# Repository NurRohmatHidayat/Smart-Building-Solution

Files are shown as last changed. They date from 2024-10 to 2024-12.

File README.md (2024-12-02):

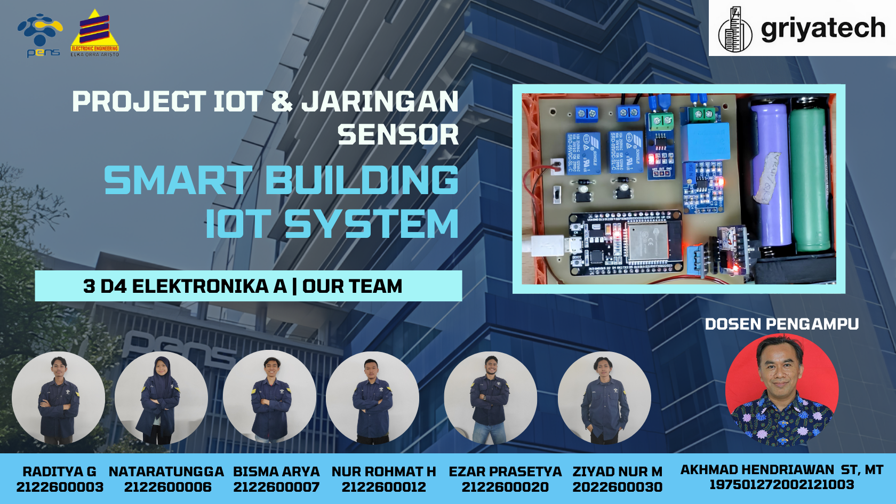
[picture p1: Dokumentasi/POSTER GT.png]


# GriyaTech
## Smart-Building-System-Berbasis IoT

Proyek ini bertujuan untuk mengembangkan sistem automasi cerdas berbasis IoT untuk Smart Building, menggunakan komponen utama seperti ESP32, RTC, dan berbagai sensor. ESP32 bertindak sebagai mikroprosesor utama yang mengontrol komunikasi antar sensor dan perangkat, memungkinkan pemantauan dan pengontrolan secara real-time melalui jaringan Wi-Fi. Sistem ini dilengkapi dengan RTC (Real-Time Clock) untuk menjaga sinkronisasi waktu, serta sensor suhu DHT11 yang digunakan untuk mengoptimalkan pengaturan suhu dan kelembaban di dalam gedung.

Untuk memantau konsumsi energi, digunakan sensor arus ACS712 dan sensor tegangan ZMPT101B yang secara akurat mengukur penggunaan listrik dan tegangan pada berbagai perangkat. Selain itu, Relay SPDT (3A 3,3V) berfungsi sebagai saklar otomatis yang memungkinkan pengendalian perangkat elektronik seperti lampu dan sistem pendingin. 

Dengan bantuan teknologi IoT, seluruh data dari sensor-sensor ini dikirimkan ke platform cloud, memungkinkan pemilik gedung untuk memantau penggunaan energi dan kondisi lingkungan secara langsung dari aplikasi mobile. Sistem ini dirancang untuk meningkatkan efisiensi energi, kenyamanan, serta keamanan penghuni gedung dengan mengotomatiskan berbagai fungsi dan memberikan kendali yang lebih fleksibel.

## Support By :
>- Dosen Pengampu : Akhmad Hendriawan ST., MT. (NIP.197501272002121003)
>- Mata kuliah : IoT dan Jaringan Sensor
>- Program Studi : D4 Teknik Elektronika
>- Politeknik Elektronika Negeri Surabaya<br>

## Team Member :
| NRP | Nama | Jobdesk | Akun |
| :---:|:---:| :---:| :-----:|
| 2122600003 | Raditya Giananta  | Hardware Developer | [Radit](https://github.com/Raditya-G)
| 2122600006 | Nataratungga Xina T | UI/UX Designer | [Ratu](https://github.com/nataratungga)
| 2122600007 | Bisma Arya Putra | Programmer | [Bisma](https://github.com/Bismaap)
| 2122600012 | Nur Rohmat Hidayat | Project Manager | [Rohmat](https://github.com/NurRohmatHidayat)
| 2122600020 | Ezar Prasetya | UI/UX Designer | [Ezar](https://github.com/EzarPrasetya)
| 2122600030 | Ziyad Nur Muhammad | 3D Designer |[Ziyad](https://github.com/Yadnur)

#### Preview Video Produk

https://github.com/user-attachments/assets/8750dca7-19aa-41fc-97a8-4954fc9a0d99

#### Preview Video Iklan 

https://github.com/user-attachments/assets/dadaf9dd-aac7-4402-b66a-3c4db6aee498

#### Preview Slide Presentasi

- [Slide Presentasi PDF](https://github.com/NurRohmatHidayat/Smart-Building-Solution/tree/main/Assets)

## Daftar Isi
- [Komponen Yang Digunakan](#Komponen-Yang-Digunakan)
- [Wiring Plan](#Wiring-Plan)
- [Hardware](#Hardware)
- [Desain 3D](#Desain-3D)
- [Program ESP32](#Program-ESP32)
- [Program Design UI/UX](#Pogram-Design-UI/UX)

## Komponen Yang Digunakan
1. **Hardware**<br>
    a. ESP32<br>
    b. Shield PCB<br>
    c. RTC<br>
    d. Sensor Suhu DHT11<br>
    e. Sensor Arus ACS712<br>
    f. Sensor Tegangan (ZMPT101B)<br>
    g. Relay SPDT (3A 3,3V)<br>

2. **Software**<br>
    a. Arduino ide<br>
    b. KiCad<br>
    c. Inventor<br>
    d. Visual Studio Code (VSC)<br>
    e. Eagle<br>

3. **Alat**<br>
    a. Solder<br>
    b. Timah solder<br>
    c. Kabel jumper<br>
    d. Breadboard<br>
    e. Obeng<br>
 
## Wiring Plan
>- First Floor Plan
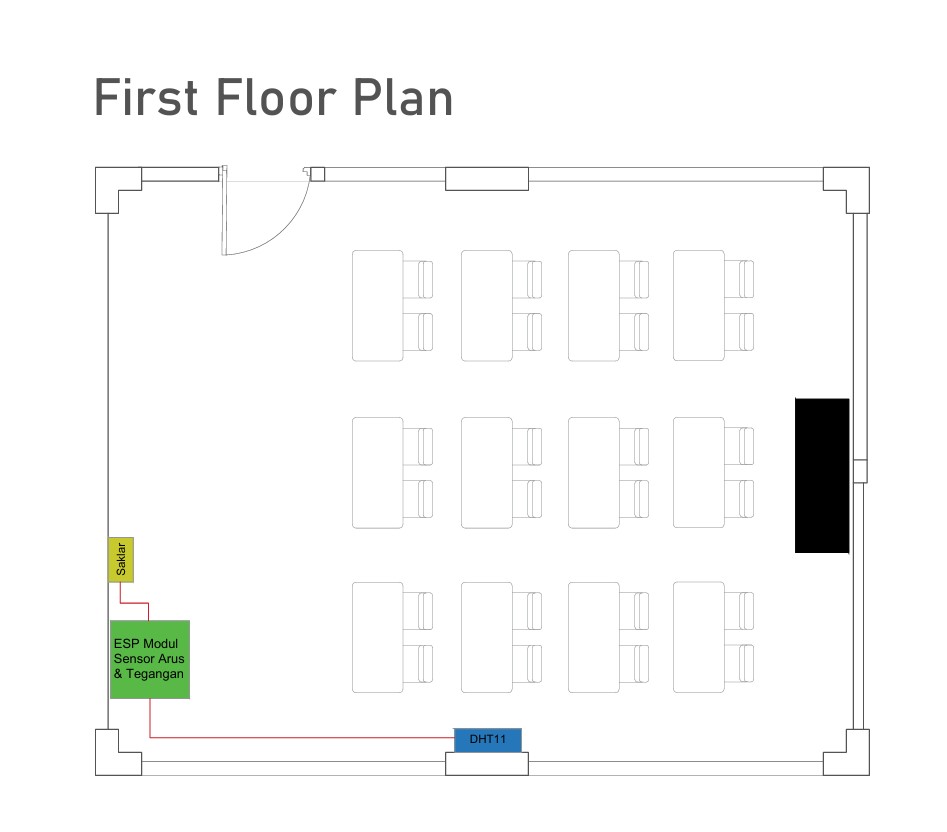
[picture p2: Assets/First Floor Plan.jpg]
>- 
>- Second Floor Plan
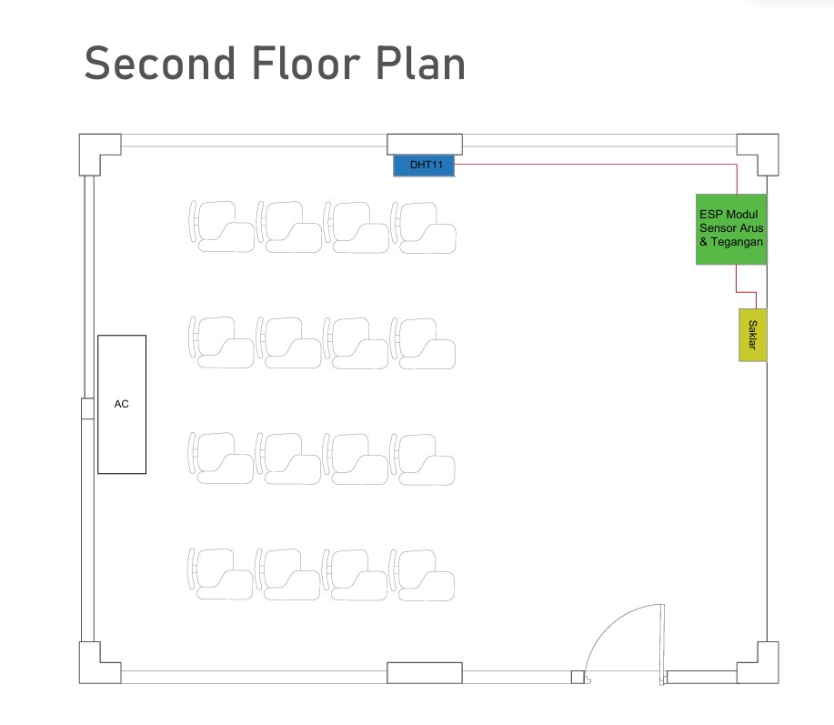
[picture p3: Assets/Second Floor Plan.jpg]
>- 

## Link YouTube 

Link youtube video produk
https://youtu.be/4Z63st0WbLA

Link youtube video iklan
https://youtu.be/mOYy9-KewV4

## [Hardware](https://github.com/NurRohmatHidayat/Smart-Building-Solution/tree/main/Hardware)

Berikut ini adalah hasil skematik rangkaian Smart Building System IoT menggunakan software KiCad.
<div align="center">
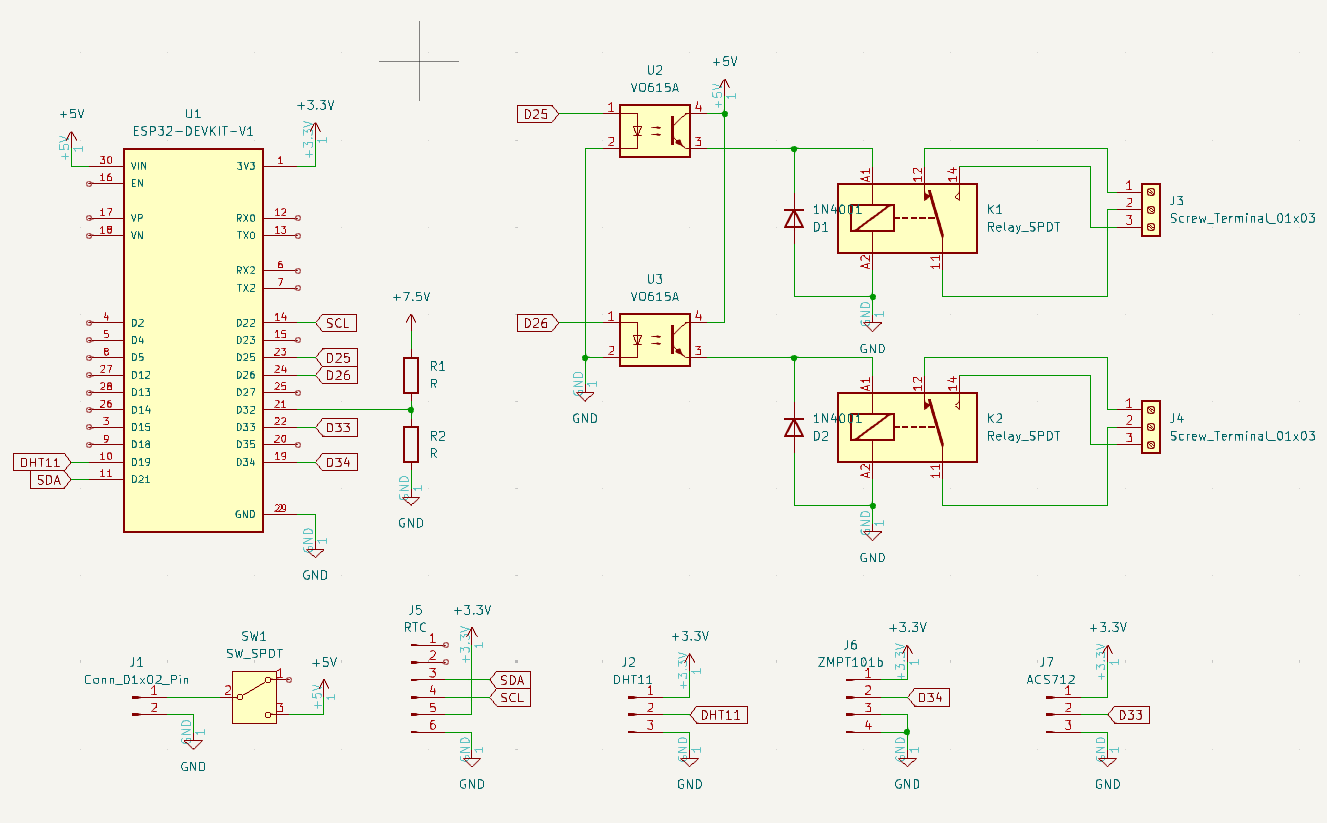
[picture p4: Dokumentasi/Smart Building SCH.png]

</div>

Berikut ini adalah hasil 3D dari  rangkaian Smart Building System IoT menggunakan software KiCad.
<div align="center">
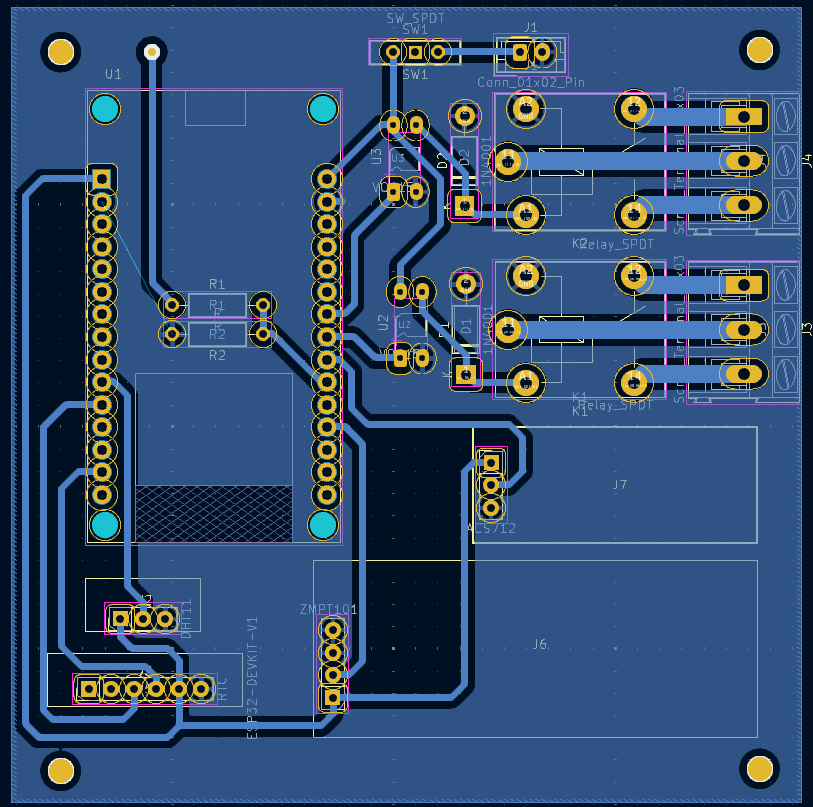
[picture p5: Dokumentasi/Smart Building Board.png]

</div>

Berikut ini adalah hasil 3D dari  rangkaian Smart Building System IoT menggunakan software KiCad.
<div align="center">
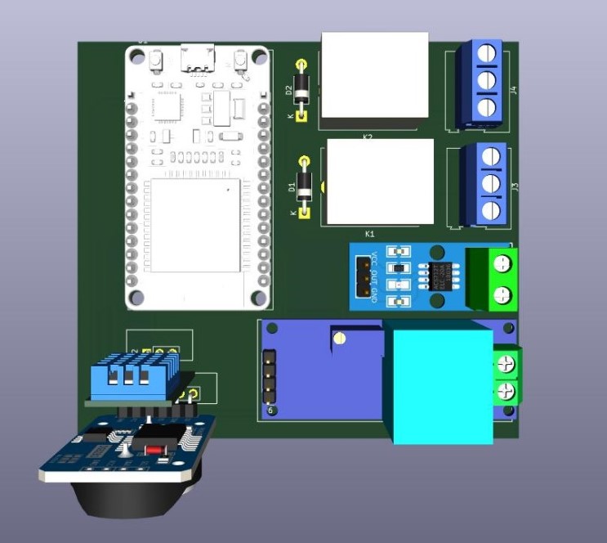
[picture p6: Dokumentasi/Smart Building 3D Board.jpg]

</div>

## [Desain 3D](https://github.com/NurRohmatHidayat/Smart-Building-Solution/tree/main/Desain%203D)

## Preview Video 3D Design

https://github.com/user-attachments/assets/e34dfbfa-0edd-4161-8904-f4dbc712b04a

Berikut adalah Link Thingivers Design 3D. Asset 3D bisa didownload pada link [Thingivers](https://www.thingiverse.com/thing:6796394)

## Diagram Block
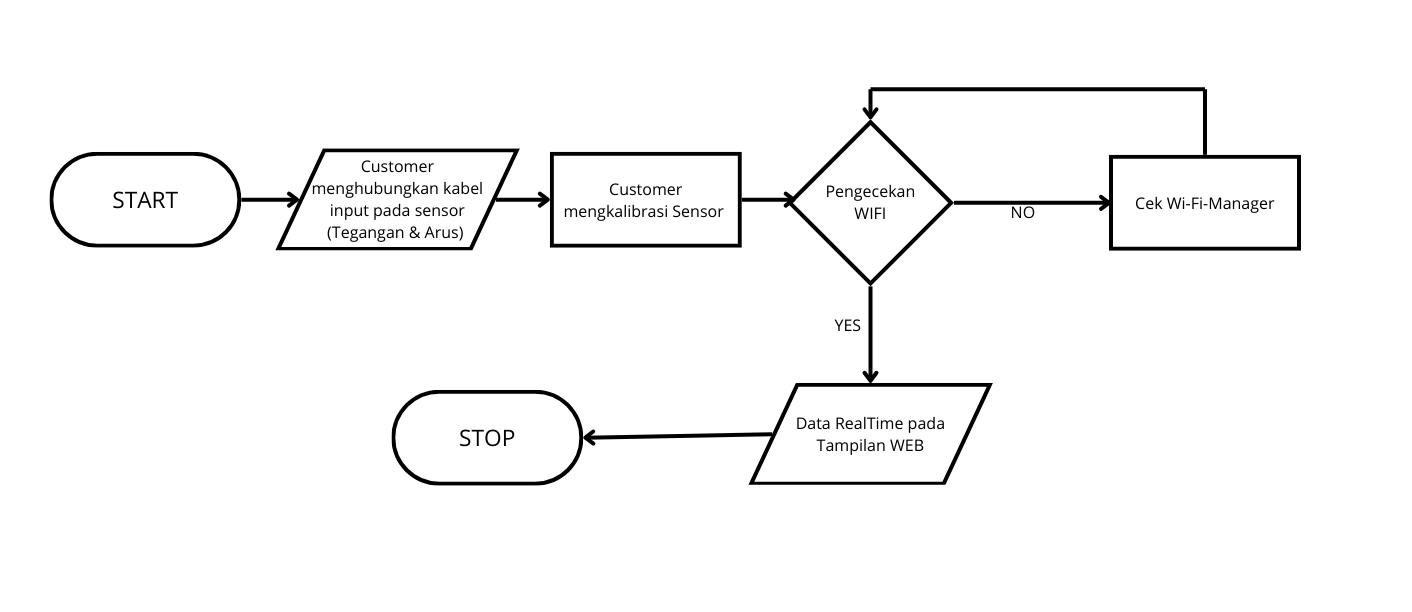
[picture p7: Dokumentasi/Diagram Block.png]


## Diagram Arsitektur System
Berikut adalah alur Diagram untuk mengirim data sensor dari publisher ke database
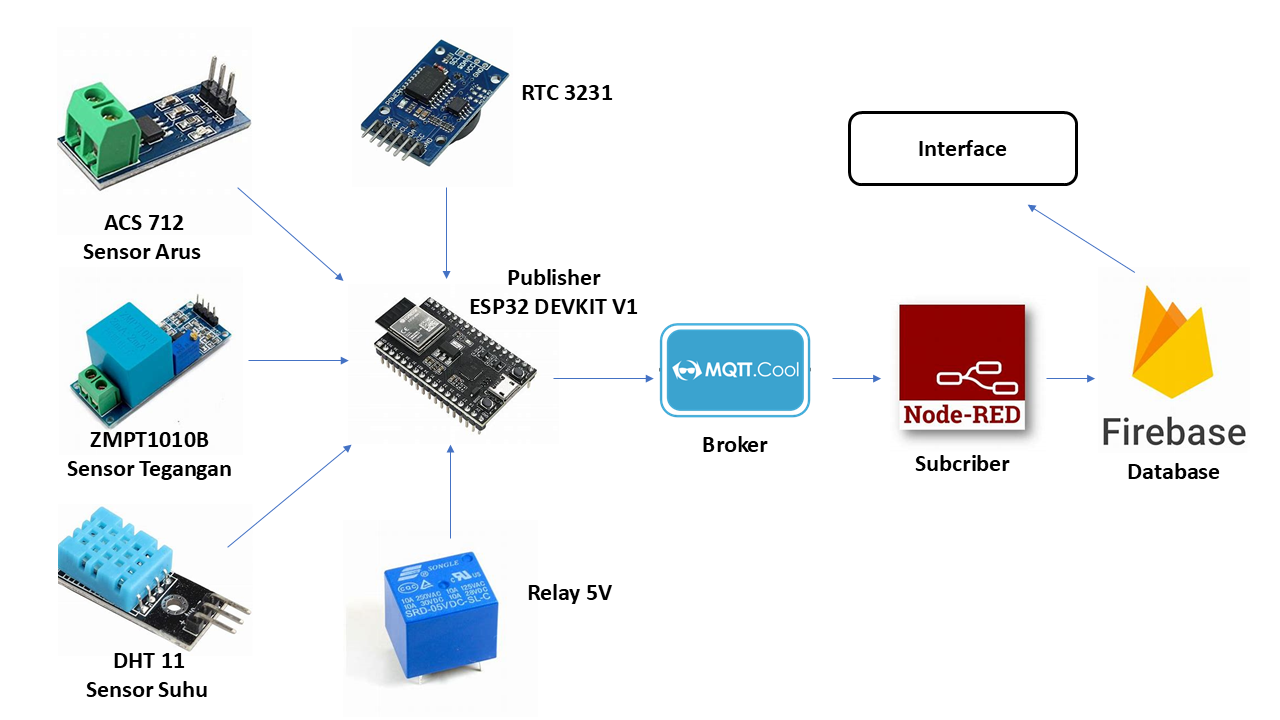
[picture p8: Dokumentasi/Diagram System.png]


## Preview Penggunaan OTA

<div align="center">

</div>

## Program ESP32

Program utama dari projek ini :
- [Arduino dengan C](https://github.com/NurRohmatHidayat/Smart-Building-Solution/tree/main/Program%20ESP32/Smart%20Building/Smart%20Building/src)

Berikut adalah video demontrasi prototype hardware. 

https://github.com/user-attachments/assets/7abacf07-8daf-47ce-86e2-667d23beedc0

Simulasi ini kami menggunakan ESP32 untuk mengontrol sensor dan modul yang terhubung di breadboard. Simulasi dilakukan menggunakan Wokwi, yang memudahkan pengujian rangkaian secara virtual sebelum implementasi fisik. Rangkaian melibatkan sensor DHT11, modul relay, LED indikator, potensiometer, dan RTC untuk sinkronisasi waktu.

Relay digunakan untuk mengontrol perangkat eksternal, sementara LED menunjukkan status sistem. Simulasi ini membantu dalam debugging dan memastikan komunikasi antar komponen berjalan baik. Meskipun Wokwi tidak menyediakan semua komponen, platform ini sangat berguna untuk pengujian dan visualisasi fungsi dasar rangkaian, membantu mengidentifikasi masalah sebelum produksi fisik.

Berikut adalah video demontrasi alat menggunakan wokwi. Klik link [Video Simulasi Software](https://youtu.be/oXDYyiHHBaU "Video Simulasi Software")

## [Alur Komunikasi]

Pada proyek ini, ESP32 menggunakan Wi-Fi Manager untuk mempermudah proses koneksi ke jaringan Wi-Fi. Wi-Fi Manager memungkinkan pengguna untuk memilih dan menghubungkan ESP32 ke jaringan internet tanpa harus mengubah kode sumber setiap kali ada perubahan pada jaringan.
Berikut tampilan pada wifi manager untuk menghubungkan ESP32 ke jaringan internet

<div align="center">
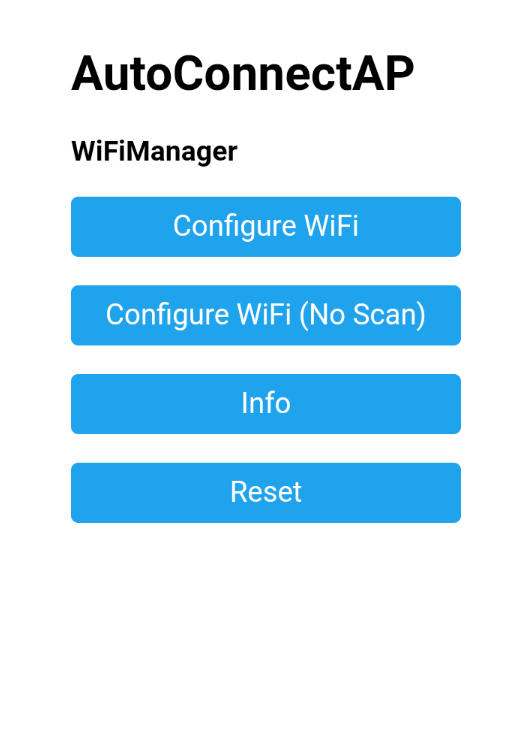
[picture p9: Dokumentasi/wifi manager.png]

</div>

Setelah ESP32 terhubung ke internet, modul ini akan mengirim data secara berkala ke broker MQTT (dalam hal ini menggunakan broker Cool MQTT). Broker MQTT berfungsi sebagai perantara yang memungkinkan ESP32 mengirim data ke sistem lain dalam arsitektur ini.
berikut tampilan broker.mqtt.cool yang menerima data sensor dari publisher ESP32
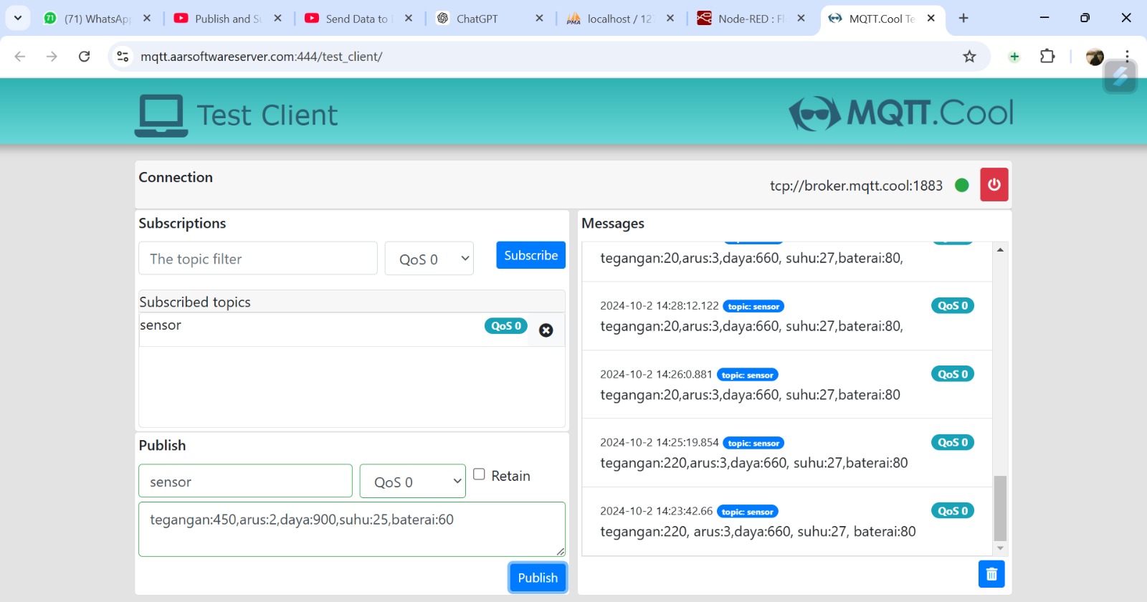
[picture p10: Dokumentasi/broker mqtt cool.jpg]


Node-RED digunakan sebagai back end untuk proyek web kami, yang berfungsi mengelola aliran data dan pemrosesannya. Data yang ditampilkan pada antarmuka web berasal dari broker MQTT di mqtt.cool, di mana Node-RED berlangganan ke topik yang relevan, memproses data sesuai kebutuhan, dan menyajikannya ke front end. Pengaturan ini memungkinkan penanganan data secara real-time dan integrasi yang efisien dengan platform web kami.

Berikut adalah alur dari program Node Red yang berfungsi untuk menerima data mqtt.cool kemudian disimpan pada database Mysql.
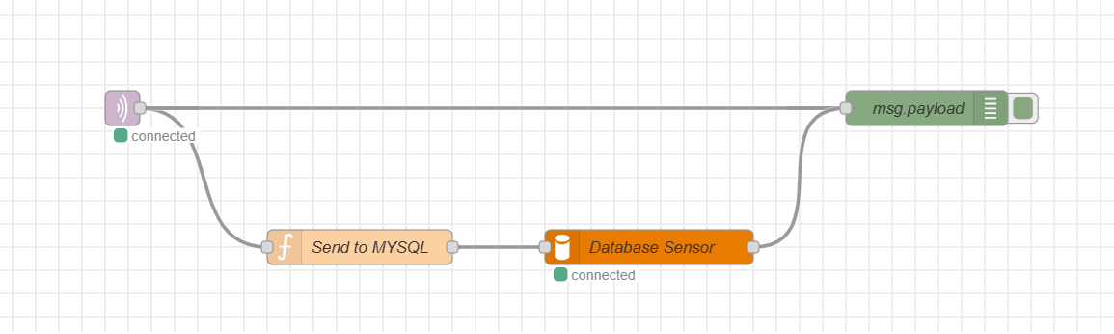
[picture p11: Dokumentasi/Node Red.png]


Berikut ini adalah program untuk Back-end Smart Building System IoT menggunakan Node-RED [Node-RED](https://github.com/NurRohmatHidayat/Smart-Building-Solution/tree/main/UI/UX%20Designer)

Berikut ini adalah program untuk WEB Smart Building System IoT menggunakan bahasa HTML [Program](https://github.com/NurRohmatHidayat/Smart-Building-Solution/tree/main/UI/UX%20Designer/node-red)

## Design Protitype Figma

<div align="center">
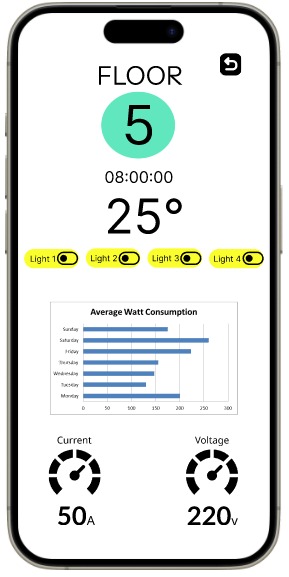
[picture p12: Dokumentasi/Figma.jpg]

</div>

## [Langkah-Langkah Penggunaan]
Berikut adalah langkah-langkah menggunakan produk "smart building" untuk para pelanggan:

1. Mengaktifkan Perangkat
  -Pastikan perangkat sudah terisi daya atau menggunakan baterai bawaan.
  -Tekan tombol Power untuk menghidupkan perangkat. Indikator lampu akan menyala sebagai tanda bahwa perangkat aktif.

2. Menghubungkan Perangkat ke Wi-Fi
  -Setelah perangkat aktif, buka smartphone atau laptop Anda.
  -Cari jaringan Wi-Fi dengan nama (ESP32_AP) sesuai perangkat, misalnya: SmartBuilding-Setup.
  -Hubungkan perangkat Anda ke Wi-Fi tersebut.
  -Secara otomatis, halaman konfigurasi Wi-Fi Manager akan terbuka. Jika tidak terbuka, buka browser dan masukkan alamat IP: 192.168.4.1.
  -Pada halaman Wi-Fi Manager:
     Pilih jaringan Wi-Fi gedung Anda.
     Masukkan kata sandi Wi-Fi.
     Klik Connect.
  -Tunggu hingga perangkat terhubung ke internet. Indikator lampu hijau akan menyala jika koneksi berhasil.

3. Memastikan Perangkat Aktif dan Berfungsi
  -Perangkat akan mulai membaca data seperti tegangan, arus, daya listrik, dan suhu ruangan.
  -Pastikan semua sensor bekerja dengan benar dengan melihat indikator status pada perangkat.

4. Mengakses Web untuk Memantau Data Sensor
  -Buka browser Anda dan masukkan alamat web yang telah diberikan, misalnya: [http://d4elkasmartbuilding.rf.gd/?i=1] atau IP tertentu.
  -Masuk ke dashboard menggunakan kredensial yang sudah disediakan.

5. Mengelola dan Memantau Data
  -Pada dashboard web, Anda dapat:
  -Melihat Data Real-Time: Tegangan, arus, daya, dan suhu.
  -Mengontrol Perangkat: Atur suhu ruangan dengan AC atau kipas.
  -Jadwalkan Lampu: Tentukan kapan lampu dinyalakan/dimatikan.
  -Semua perubahan yang Anda lakukan akan langsung diterapkan pada perangkat.

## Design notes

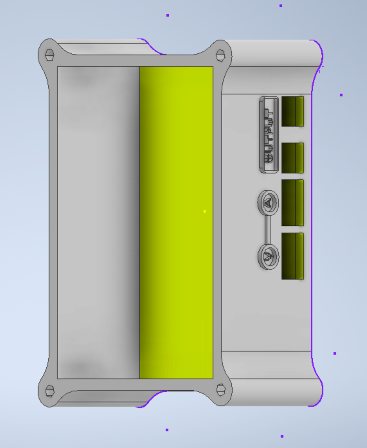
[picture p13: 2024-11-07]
Dokumentasi/BOX_Hardware.png

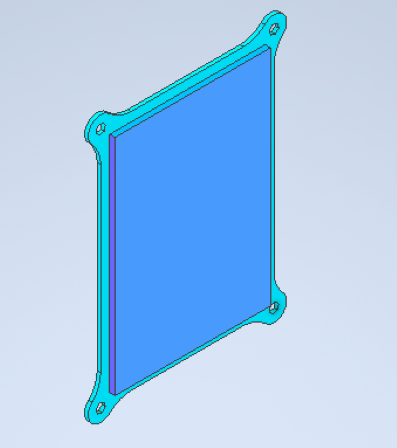
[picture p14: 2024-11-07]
Dokumentasi/Design Atas.png

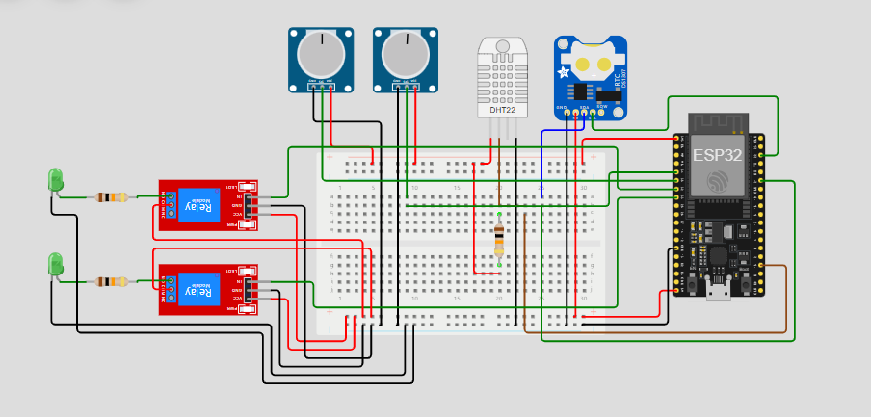
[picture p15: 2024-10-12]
Dokumentasi/Rangkaian Module_Wokwi.png

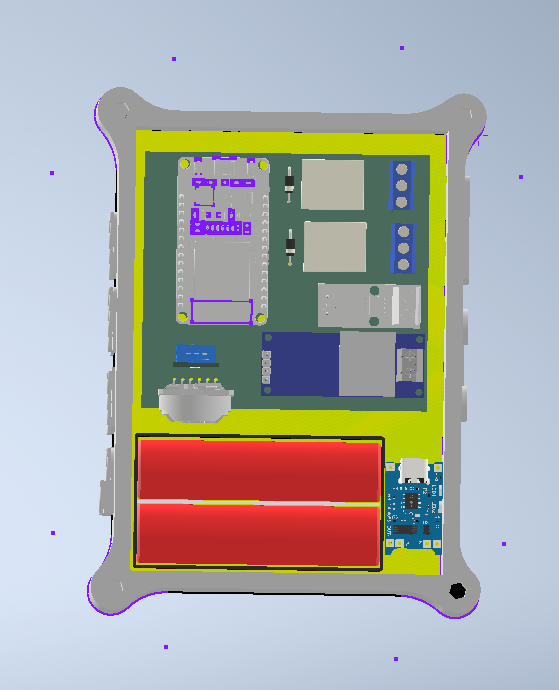
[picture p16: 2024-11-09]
Dokumentasi/UsingKomponen.png

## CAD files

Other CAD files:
Desain 3D/Cover_Box.ipt
Desain 3D/SmartBuildingBox.iam
Desain 3D/Smart_Building_Box.ipt

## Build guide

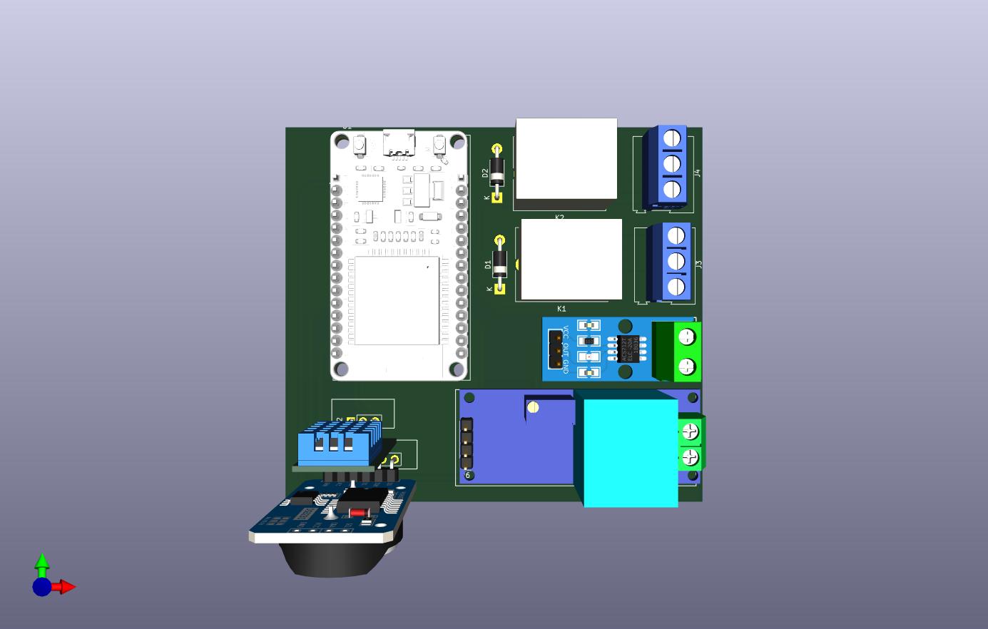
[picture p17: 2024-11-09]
Assets/Smart Building Full.jpg

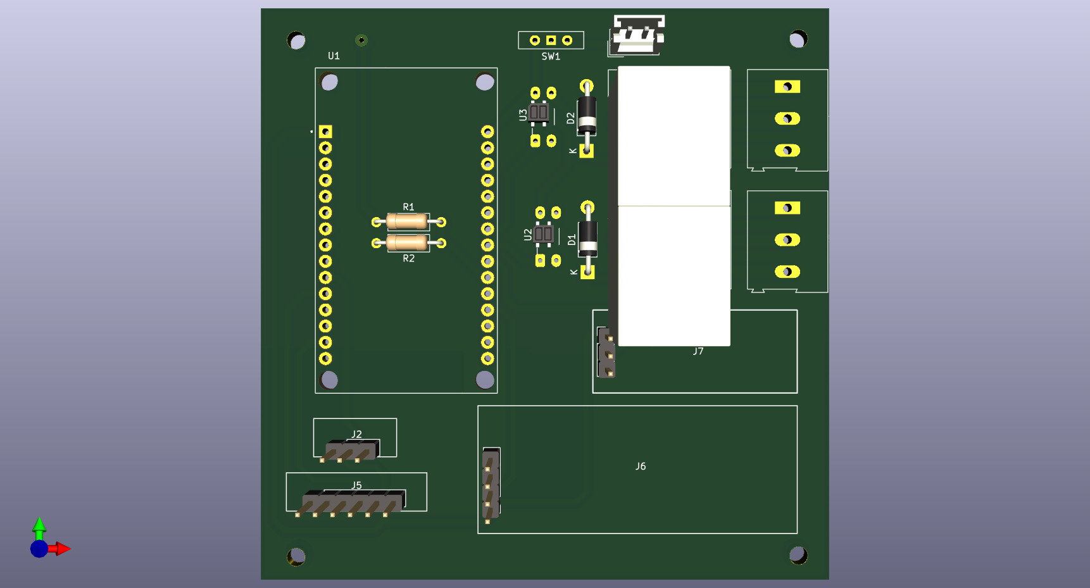
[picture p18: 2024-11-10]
Dokumentasi/Smart Building.png

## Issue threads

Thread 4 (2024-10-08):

3D Designer

NurRohmatHidayat, 2024-10-08:
◦ Desain 3D dari shield ESP selesai dibuat.
        ◦ Screenshot 3D image di-upload ke GitHub.
        ◦ 3D desain di-upload ke Thingiverse (tautan disertakan di GitHub).

Closed 2024-10-13.

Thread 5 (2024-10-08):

Finalisasi Konsep

NurRohmatHidayat, 2024-10-08:
• Konsep produk diperbarui berdasarkan feedback dari minggu sebelumnya.
    • Revisi tujuan produk dan fungsionalitas utama.
   ◦ Video demonstrasi alat di Wokwi diunggah ke YouTube (tautan disertakan di GitHub).

Closed 2024-10-13.

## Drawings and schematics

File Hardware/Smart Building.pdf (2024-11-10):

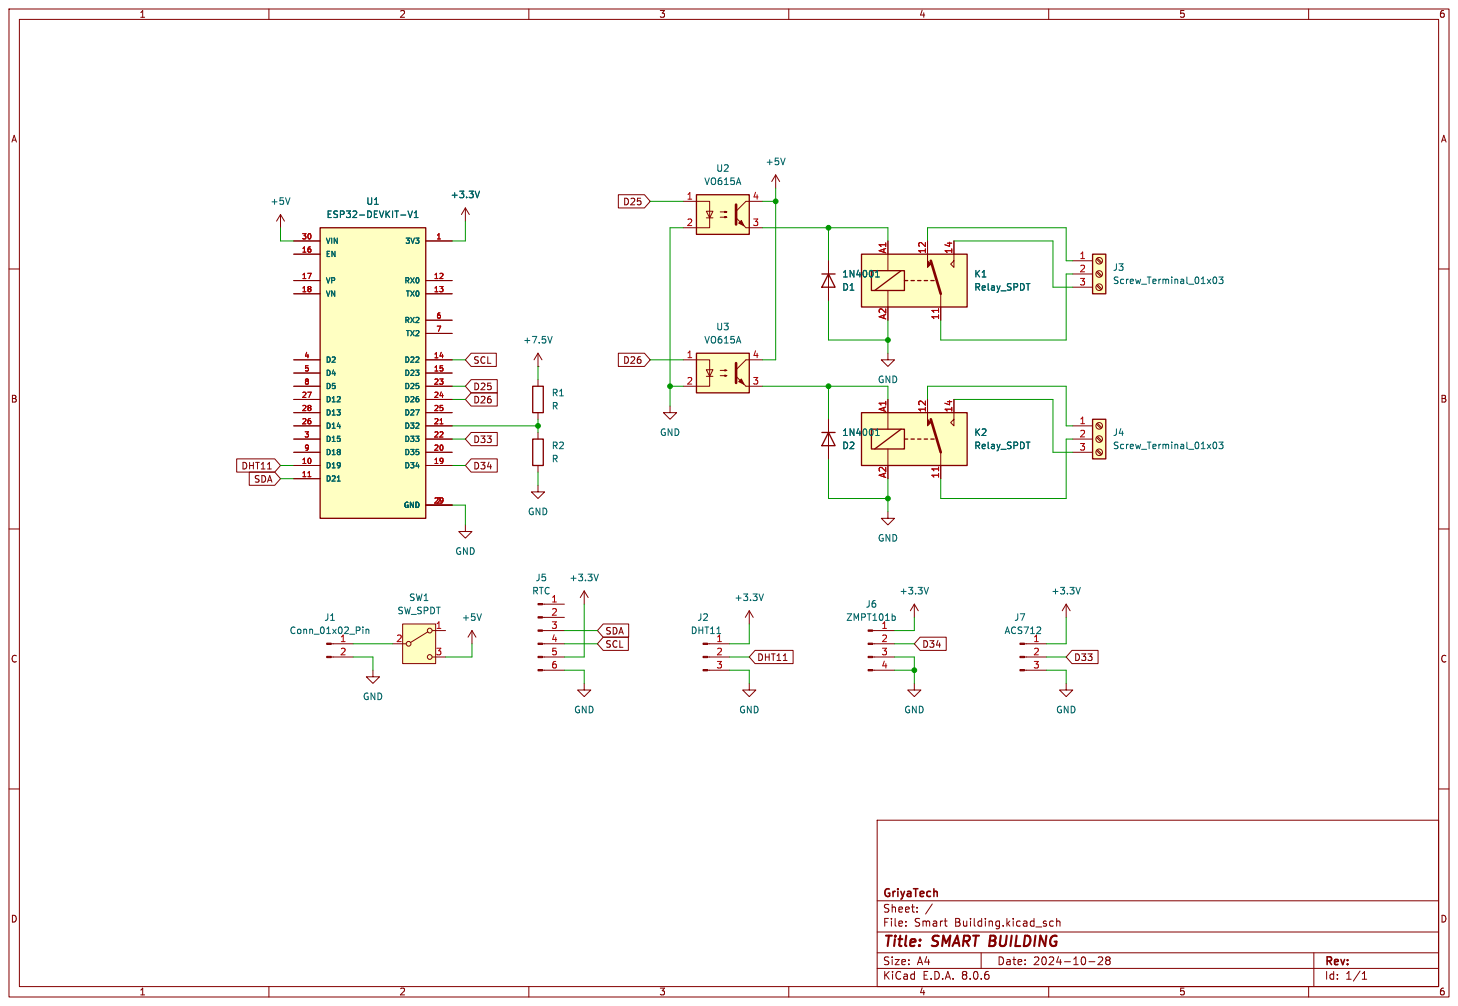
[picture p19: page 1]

Id: 1/1 Title: SMART BUILDING

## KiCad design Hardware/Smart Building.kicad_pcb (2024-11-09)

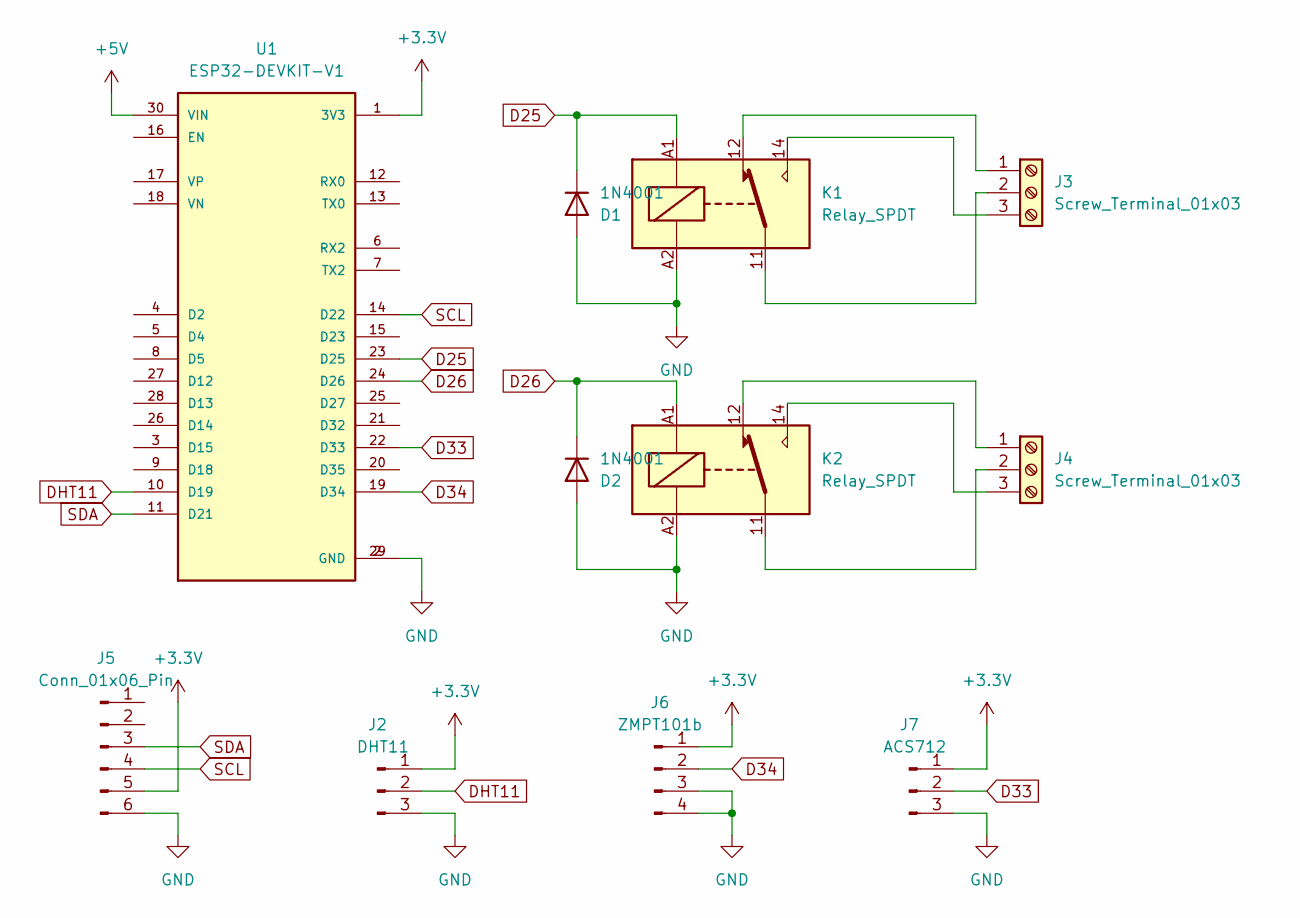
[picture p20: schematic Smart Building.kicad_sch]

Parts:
D1, D2: 1N4001; D_DO-41_SOD81_P10.16mm_Horizontal
J2: DHT11; PinHeader_1x03_P2.54mm_Vertical
J3, J4: Screw_Terminal_01x03; TerminalBlock_Altech_AK300-3_P5.00mm
J5: Conn_01x06_Pin; PinHeader_1x06_P2.54mm_Vertical
J6: ZMPT101b; PinHeader_1x04_P2.54mm_Vertical
J7: ACS712; PinHeader_1x03_P2.54mm_Vertical
K1, K2: Relay_SPDT; Relay_SPDT_Finder_36.11
U1: ESP32-DEVKIT-V1; MODULE_ESP32_DEVKIT_V1; PARTREV N/A

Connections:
+3.3V: J2.1, J5.5, J6.1, J7.1, U1.1 (3V3)
+5V: U1.30 (VIN)
D25: D1.1 (K), K1.A1, U1.23 (D25)
D26: D2.1 (K), K2.A1, U1.24 (D26)
D33: J7.2, U1.22 (D33)
D34: J6.2, U1.19 (D34)
DHT11: J2.2, U1.10 (D19)
GND: D1.2 (A), D2.2 (A), J2.3, J5.6, J6.3, J6.4, J7.3, K1.A2, K2.A2, U1.2 (GND), U1.29 (GND)
unnamed: J3.1, K1.12
unnamed: J3.2, K1.11
unnamed: J3.3, K1.14
unnamed: J4.1, K2.12
unnamed: J4.2, K2.11
unnamed: J4.3, K2.14
SCL: J5.4, U1.14 (D22)
SDA: J5.3, U1.11 (D21)

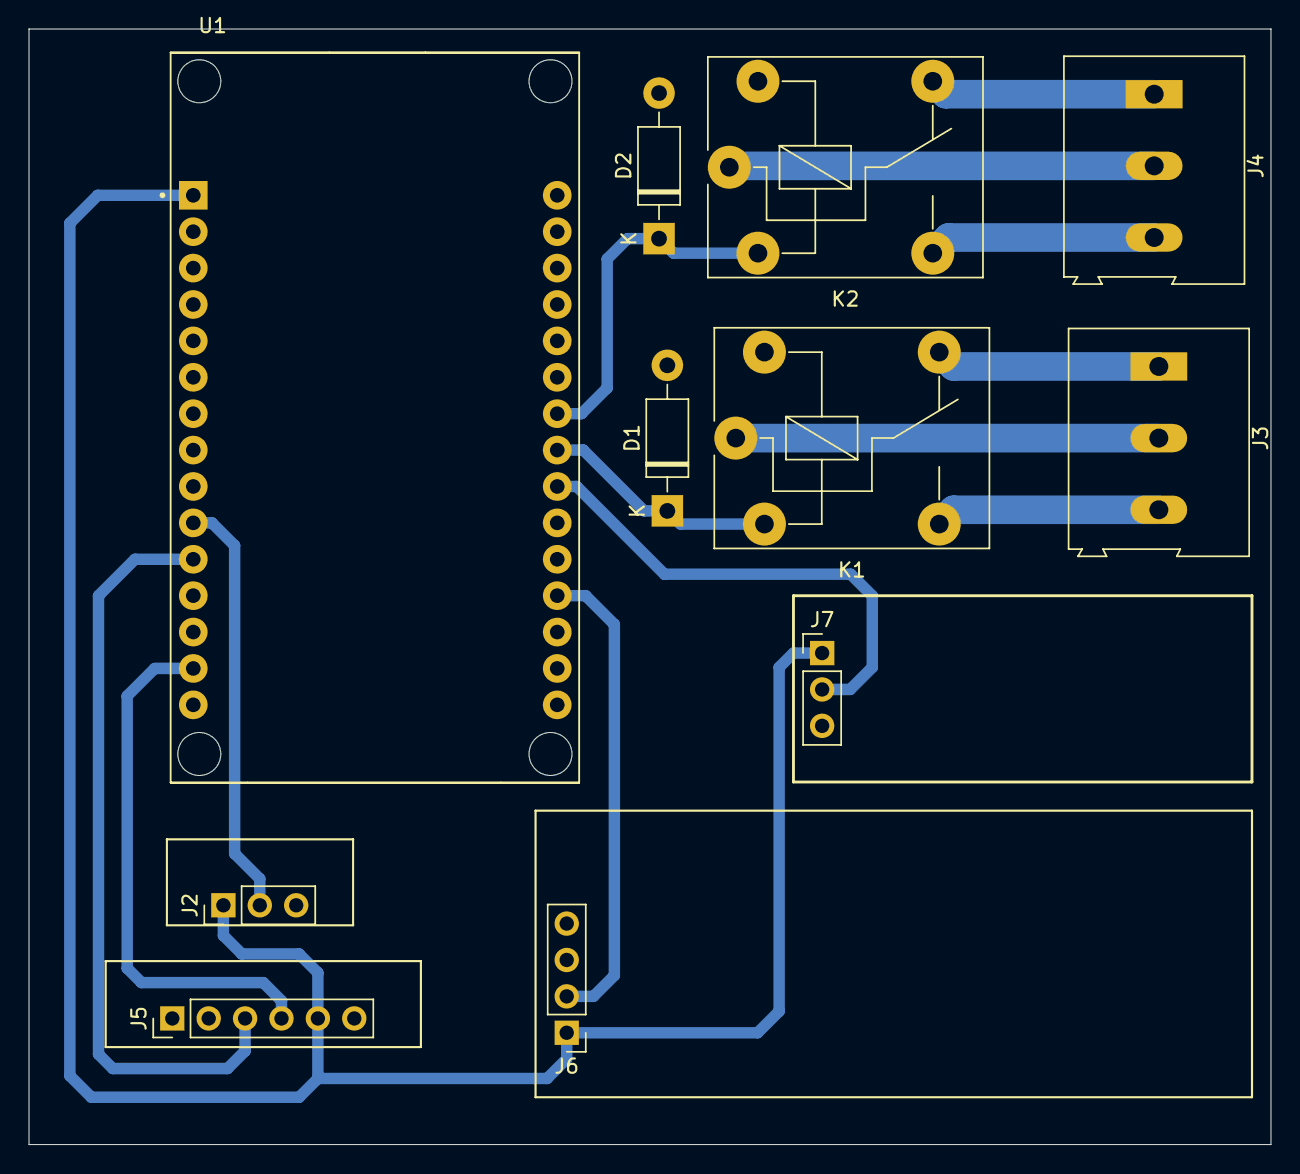
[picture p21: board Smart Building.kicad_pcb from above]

Board: 2 copper layers, 86.7 x 77.9 mm, 11 parts (0 on the bottom side), 15 nets.

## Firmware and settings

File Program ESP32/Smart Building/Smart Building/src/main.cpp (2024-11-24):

#include <WiFiManager.h>        // Library WiFiManager
#include <PubSubClient.h>       // Library MQTT
#include <Wire.h>               // I2C untuk RTC
#include <RTClib.h>
#include <EduIntro.h>
#include <ZMPT101B.h>
#include <ACS712.h>
#include <WebServer.h>          // Server Web untuk ElegantOTA
#include <ElegantOTA.h>         // Library ElegantOTA
 
#define RELAY_AC 25 
#define RELAY_LAMP 26 

// Inisialisasi sensor DHT
DHT11 dht11(19);

// Inisialisasi RTC
RTC_DS1307 rtc;


// Fungsi untuk menghitung kWh
float calculateKWH(float voltage, float current) {
  return (voltage * current); 
}


// MQTT broker dan topic
const char* mqtt_server = "broker.mqtt.cool"; 

// Inisialisasi WiFi dan MQTT
WiFiClient espClient;
PubSubClient client(espClient);
WiFiManager wifiManager;
WebServer server(80); // ElegantOTA menggunakan server ini

// Fungsi untuk menghubungkan ke broker MQTT
void reconnect() {
  if (!client.connected()) {
    if (client.connect("ESP32Client")) {
      // Jika terkoneksi, subscribe ke topik yang diperlukan
      client.subscribe("sensor/#");
    } else {
      delay(5000);  // Tunggu 5 detik sebelum mencoba lagi
    }
  }
}

void setup() {
  Serial.begin(115200);
  Serial.println(F("Sensor Monitoring!"));

  // Memulai RTC
  Wire.begin();
  rtc.begin();

  // mengatur pin relay sebagai output
  pinMode(RELAY_AC, OUTPUT);
  pinMode(RELAY_LAMP, OUTPUT);

  //Matikan relay pada awalnya
  digitalWrite(RELAY_AC, HIGH);
  digitalWrite(RELAY_LAMP, HIGH);

  // Inisialisasi WiFiManager dan PubSubClient
  wifiManager.autoConnect("Griya_Tech");

  if (!WiFi.isConnected()) {
    Serial.println("Failed to connect to WiFi. OTA will not work.");
  } else {
    Serial.println("WiFi connected successfully");
    Serial.print("IP Address: ");
    Serial.println(WiFi.localIP());
  }

  
  client.setServer(mqtt_server, 1883);

   // Inisialisasi ElegantOTA
  ElegantOTA.begin(&server);
  server.begin();
  Serial.println("ElegantOTA ready! Access at: http://" + WiFi.localIP().toString() + "/update");
}

unsigned long previousMillis = 0;
const long interval = 2000;

void loop() {
  server.handleClient(); // Menangani permintaan dari ElegantOTA

  // Hubungkan ulang ke broker jika tidak terhubung
  if (!client.connected()) {
    reconnect();
  }
  client.loop();

  // Interval untuk loop utama
  unsigned long currentMillis = millis();
  if (currentMillis - previousMillis >= interval) {
    previousMillis = currentMillis;

    // Tambahan kode utama Anda
      float humidity = 0;
      float temperature = 0;
      dht11.update();
      // Membaca kelembaban
      humidity = dht11.readHumidity();
      // Membaca suhu dalam Celsius
      temperature = dht11.readCelsius();

      ///////////////////////////////////TEGANGAN////////////////////////////
      float sum = 0;
      for (int i = 0; i < 500; i++) {
        int adcValue2 = analogRead(34);  // Baca nilai ADC
        float voltage = (adcValue2 * 3.3) / 4095;  // Konversi ke tegangan
        float centeredVoltage = voltage - (3.3 / 2); // Pusatkan di sekitar 0
        sum += centeredVoltage * centeredVoltage;
        delay(1);  // Beri jeda kecil antara sampel
      }
      // Hitung nilai RMS
      float rmsVoltage = sqrt(sum / 500);
      float volt = rmsVoltage / 0.00127045; // Konversi ke tegangan AC menggunakan faktor kalibrasi
      float U = (volt <= 120) ? 0 : volt;
      ///////////////////////////////////////////////////////////////////////


      //////////////////////////////ARUS////////////////////////////////////////////
      int adcValue_1 = analogRead(33);
      // Mengonversi nilai ADC ke tegangan
      float arus = (adcValue_1 * 3.3) / 4095;
      // Menghitung arus dalam ampere
      // Sensitivitas untuk ACS712-20A adalah 100mV/A (0.1 V per ampere)
      float sensitivity = (20.0 == 5) ? 0.185 : (20.0 == 20) ? 0.1 : 0.066;
      float I = (arus - 1.2) / sensitivity;
      ///////////////////////////////////////////////////////////////////////////////

      // Menghitung kWh
      float kWh = calculateKWH(U, I);

      // Mengambil waktu dari RTC
      DateTime now = rtc.now();

      // Periksa apakah ada pembacaan yang gagal dari DHT22
      if (isnan(humidity) || isnan(temperature)) {
        Serial.println(F("Failed to read from DHT sensor!"));
        return;
      }

      // Pengaturan relay untuk AC berdasarkan suhu
      if (temperature < 30) {
        digitalWrite(RELAY_AC, LOW);  
        Serial.println(F("AC/LED OFF (Suhu < 30°C)"));
      } else if (temperature >= 30) {
        digitalWrite(RELAY_AC, HIGH);   
        Serial.println(F("AC/LED ON (Suhu >= 30°C)"));
      }

      // Pengaturan relay untuk lampu berdasarkan waktu 
      if  (now.hour() >= 8 && now.hour() < 20){
        digitalWrite(RELAY_LAMP, LOW);  
        Serial.println(F("Lampu Ruangan OFF "));
      } else {
        digitalWrite(RELAY_LAMP, HIGH); 
        Serial.println(F("Lampu Ruangan ON "));
      }


    //////////////////////////////BATERY//////////////////////////////////////////
      int adcValue = analogRead(32); // Ganti dengan pin yang digunakan
      float voltageOut = adcValue * 3.3 / 4095.0;
      float batteryVoltage = voltageOut * 9.2; // Pembalik dari pembagi tegangan
      float batteryPercentage = (batteryVoltage - 3.0) / (4.2 - 3.0) * 100.0;
      if (batteryPercentage > 1000.0) {
        batteryPercentage = 100.0;
    } else if (batteryPercentage < 0.0) {
        batteryPercentage = 0.0;
    }
      float Vbaterai = batteryPercentage;
    ///////////////////////////////////////////////////////////////////////////////////

    //////////////// Cetak hasil pembacaan ke Serial Monitor//////////////////////////
      Serial.print(F("Humidity: "));
      Serial.print(humidity);
      Serial.print(F("%  Temperature: "));
      Serial.print(temperature);
      Serial.println(F("°C"));

      // Cetak pembacaan tegangan dan arus
      Serial.print(F("Voltage: "));
      Serial.print(U, 2); 
      Serial.print(F(" V, Current: "));
      Serial.print(I, 2);
      Serial.print(F(" A, Estimated KWH: "));
      Serial.print(kWh, 2); 
      Serial.println(F(" kWh"));  
      Serial.print(F("Battery: "));
      Serial.print(Vbaterai, 2); 


    String dataMessage ="tegangan:" + String(U) + "," + 
                        "arus:" + String(I) + "," + 
                        "daya:" + String(kWh) + "," + 
                        "suhu:" + String(temperature) + "," + 
                        "baterai:" + String(Vbaterai);
      // Kirim data ke broker MQTT
      client.publish("sensor", dataMessage.c_str());
  }
}

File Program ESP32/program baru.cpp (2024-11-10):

#include <WiFiManager.h>        // Library WiFiManager
#include <PubSubClient.h>       // Library MQTT
#include <Wire.h>               // I2C untuk RTC
//#include <Adafruit_Sensor.h>    // Sesuaikan jika ada sensor spesifik untuk tegangan dan arus
//#include <Adafruit_BME280.h>    // Contoh jika ada sensor tegangan (ganti sesuai sensor kamu)

#include "DHT.h"

//********//
#define DHTPIN 15      // Pin data sensor DHT22 terhubung ke GPIO 15 ESP32
#define DHTTYPE DHT22  // DHT22 (AM2302)
#define VOLTAGE_PIN 34 // Pin potensiometer untuk tegangan terhubung ke GPIO 34 (A0)
#define CURRENT_PIN 35  // Pin potensiometer untuk arus terhubung ke GPIO 35 (A1)
#define RELAY_AC 32 // Pin relay untuk AC terhubung ke GPIO32
#define RELAY_LAMP 33 // Pin relay untuk lampu ruangan terhubung ke GPIO33

// Inisialisasi sensor DHT
DHT dht(DHTPIN, DHTTYPE);

// Inisialisasi RTC
RTC_DS1307 rtc;

// Fungsi untuk mengonversi nilai potensiometer ke volt (0 - 5V)
float convertPotToVoltage(int potValue) {
  return (potValue / 4095.0) * 5.0; // Mengubah nilai potensiometer ke volt
}

// Fungsi untuk mengonversi nilai potensiometer ke arus (0 - 5A)
float convertPotToCurrent(int potValue) {
  return (potValue / 4095.0) * 5.0; // Mengubah nilai potensiometer ke arus (misalnya 0 - 5A)
}

// Fungsi untuk menghitung kWh
float calculateKWH(float voltage, float current) {
  // Menghitung kWh dengan rumus: (Voltage * Current) * Time
  // Di sini kita anggap waktu = 1 jam (1 kWh = 1 Volt * 1 Ampere * 1 jam)
  return (voltage * current); // kWh = Volt * Ampere
}

//*******//

//// Pin untuk pengukuran
//const int voltagePin = 34;      // Pin untuk mengukur tegangan (sesuaikan pin)
//const int currentPin = 35;      // Pin untuk mengukur arus (sesuaikan pin)

// MQTT broker dan topic
const char* mqtt_server = "broker.mqtt.cool"; 
const char* topic_voltage = "sensor/voltage";
const char* topic_current = "sensor/current";
const char* topic_battery = "sensor/battery";

// Inisialisasi WiFi dan MQTT
WiFiClient espClient;
PubSubClient client(espClient);
WiFiManager wifiManager;

//// Fungsi untuk membaca sensor tegangan
//float readVoltage() {
//  int analogValue = analogRead(voltagePin);
//  float voltage = analogValue * (3.3 / 4096.0) * 11;  // Sesuaikan faktor kalibrasi sensor tegangan
//  return voltage;
//}
//
//// Fungsi untuk membaca sensor arus
//float readCurrent() {
//  int analogValue = analogRead(currentPin);
//  float current = analogValue * (3.3 / 4096.0) * 5;   // Sesuaikan dengan sensor arus yang dipakai
//  return current;
//}

// Fungsi untuk menghubungkan ke broker MQTT
void reconnect() {
  while (!client.connected()) {
    if (client.connect("ESP32Client")) {
      // Jika terkoneksi, subscribe ke topik yang diperlukan
      client.subscribe("sensor/#");
    } else {
      delay(5000);  // Tunggu 5 detik sebelum mencoba lagi
    }
  }
}

void setup() {
  Serial.begin(115200);
  Serial.println(F("Sensor Monitoring!"));

  // Memulai sensor DHT
  dht.begin();

  // Memulai RTC
  Wire.begin();
  rtc.begin();

  // mengatur pin relay sebagai output
  pinMode(RELAY_AC, OUTPUT);
  pinMode(RELAY_LAMP, OUTPUT);

  //Matikan relay pada awalnya
  digitalWrite(RELAY_AC, HIGH);
  digitalWrite(RELAY_LAMP, HIGH);

  // Inisialisasi WiFiManager dan PubSubClient
  wifiManager.autoConnect("ESP32_AP");

  if (!wifiManager.autoConnect("ESP32_AP")) {
    Serial.println("Failed to connect to WiFi");
  } else {
    Serial.println("WiFi connected successfully");
    Serial.println("IP Address: ");
    Serial.println(WiFi.localIP());
  }
  
  client.setServer(mqtt_server, 1883);
}

void loop() {
  // Hubungkan ulang ke broker jika tidak terhubung
  if (!client.connected()) {
    reconnect();
  }
  client.loop();

  // Membaca kelembaban
  float humidity = dht.readHumidity();
  // Membaca suhu dalam Celsius
  float temperature = dht.readTemperature();

  // Membaca potensiometer untuk tegangan dan arus
  int voltagePotValue = analogRead(VOLTAGE_PIN);   // Baca nilai potensiometer tegangan
  int currentPotValue = analogRead(CURRENT_PIN);    // Baca nilai potensiometer arus

  // Mengonversi potensiometer ke nilai volt dan arus
  float voltage = convertPotToVoltage(voltagePotValue); // Konversi ke Volt
  float current = convertPotToCurrent(currentPotValue);   // Konversi ke Ampere

  // Menghitung kWh
  float kWh = calculateKWH(voltage, current);

  // Mengambil waktu dari RTC
  DateTime now = rtc.now();

  // Periksa apakah ada pembacaan yang gagal dari DHT22
  if (isnan(humidity) || isnan(temperature)) {
    Serial.println(F("Failed to read from DHT sensor!"));
    return;
  }

  // Pengaturan relay untuk AC berdasarkan suhu
  if (temperature < 16) {
    digitalWrite(RELAY_AC, LOW);  // Matikan AC (relay OFF)
    Serial.println(F("AC/LED OFF (Suhu < 16°C)"));
  } else if (temperature >= 27) {
    digitalWrite(RELAY_AC, HIGH);   // Nyalakan AC (relay ON)
    Serial.println(F("AC/LED ON (Suhu >= 27°C)"));
  }

  // Pengaturan relay untuk lampu berdasarkan waktu (antara jam 15:00 sampai 16:00)
  if (now.hour() >= 17 && now.hour() < 6) {
    digitalWrite(RELAY_LAMP, LOW);  // Nyalakan lampu (relay ON)
    Serial.println(F("Lampu Ruangan ON (Jam >= 17:00 dan < 6:00)"));
  } else {
    digitalWrite(RELAY_LAMP, HIGH); // Matikan lampu di luar jam 15:00 - 16:00 (relay OFF)
    Serial.println(F("Lampu Ruangan OFF (Di luar waktu 17:00 - 6:00)"));
  }

  // Cetak hasil pembacaan ke Serial Monitor
  Serial.print(F("Humidity: "));
  Serial.print(humidity);
  Serial.print(F("%  Temperature: "));
  Serial.print(temperature);
  Serial.println(F("°C"));

  // Cetak pembacaan tegangan dan arus
  Serial.print(F("Voltage: "));
  Serial.print(voltage, 2); // Tampilkan 2 angka desimal
  Serial.print(F(" V, Current: "));
  Serial.print(current, 2); // Tampilkan 2 angka desimal
  Serial.print(F(" A, Estimated KWH: "));
  Serial.print(kWh, 2); // Tampilkan 2 angka desimal
  Serial.println(F(" kWh"));

  // Baca data tegangan, arus, dan baterai RTC
//  float voltage = readVoltage();
//  float current = readCurrent();
//  float batteryVoltage = 3.7;  // Ganti dengan pembacaan RTC jika ada

  // Kirim data ke broker MQTT
  client.publish(topic_voltage, String(voltage).c_str());
  client.publish(topic_current, String(current).c_str());
  client.publish(topic_current, String(kWh).c_str());
  client.publish(topic_battery, String(temperature).c_str());

  delay(4000);  // Kirim setiap 5 detik

  
}

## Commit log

2024-10-08 Rangkaian Modul pada Wokwi
    Rangkaian yang digunakan untuk simulasi modul ESP32
2024-10-09 add schematic and pcb board
    [Smart Building.kicad_pcb, Smart Building.kicad_sch]
2024-10-09 add program esp32
2024-10-12 Menambahkan 2 Relay
    Menambahkan 2 Relay dan 2 LED untuk menggantikan AC dan lampu ruangan
2024-10-12 menambahkan 2 Relay
2024-10-13 menambahkan program untuk kedua relay
2024-10-20 adding hardware component in 3D Design and file 3D
    [SmartBuildingBox.iam]
2024-10-21 memperbarui schematic dan board dengan menambahkan switch dan connector untuk baterai
2024-11-09 Final (#36)
    * merapihkan gambar yang ada pada readme
    * menambahkan foder platform.io
    * memperbaiki branch
    * memperbaiki branch
    [Smart Building.kicad_pcb, Smart Building.kicad_sch]
2024-11-09 Update File 3D Design Inventor
    [Cover_Box.ipt, Smart_Building_Box.ipt]
2024-11-10 Hardware (#38)
    * memperbarui schematic dan board dengan menambahkan switch dan connector untuk baterai
    * memperbarui schematic dan board dengan menambahkan switch dan connector untuk baterai
    * memperbarui rangkaian chematic dan board dengan menambahkan sensor tegangan baterai
    * memperbarui rangkaian chematic dan board dengan menambahkan opto coupler pc817 untuk mengaktifkan relay yang membutuhkan supply 5v
    * memperbarui rangkaian schematic dan board dengan menambahkan opto coupler pc817 untuk mengaktifkan relay yang membutuhkan supply 5v
    ---------
    [Smart Building.kicad_sch]
2024-11-10 Update README.md
    menambahkan block diagram komunikasi untuk mengirim data sensor dari publisher ke database
2024-11-10 Update README.md
    menambahkan deskripsi untuk menghubungkan esp32 ke jaringan internet menggunakan wifi manager
2024-11-10 Update README.md
    menambahkan deskripsi proses kirim data sensor ke broker mqtt cool pada alur komunikasi
2024-11-11 Update README.md
    menambahkan tampilan broker mqtt cool yang berhasil meneripa data sensor dari sensor dari publisher
2024-11-24 adding Code OTA for ESP32
2024-12-02 Menambah foto Cetak 3D Print
